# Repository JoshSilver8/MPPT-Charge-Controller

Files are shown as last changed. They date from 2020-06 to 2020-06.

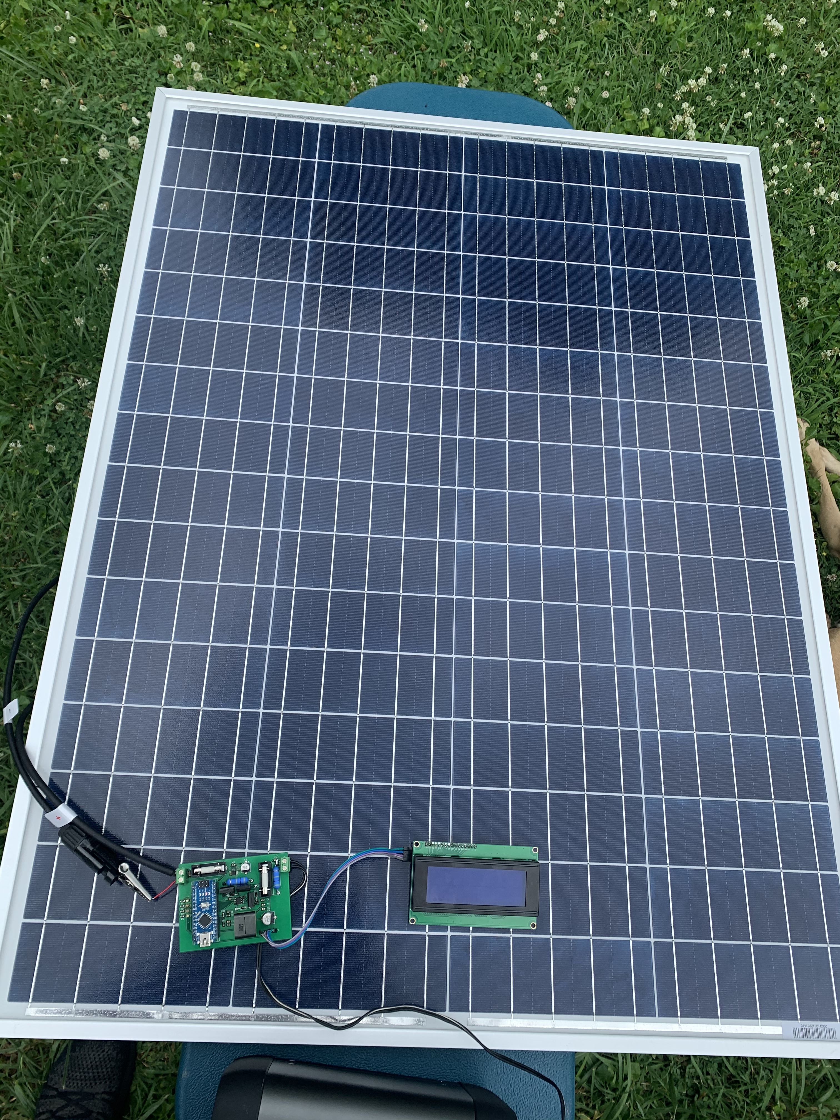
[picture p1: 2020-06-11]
Photos/Test 1.JPG

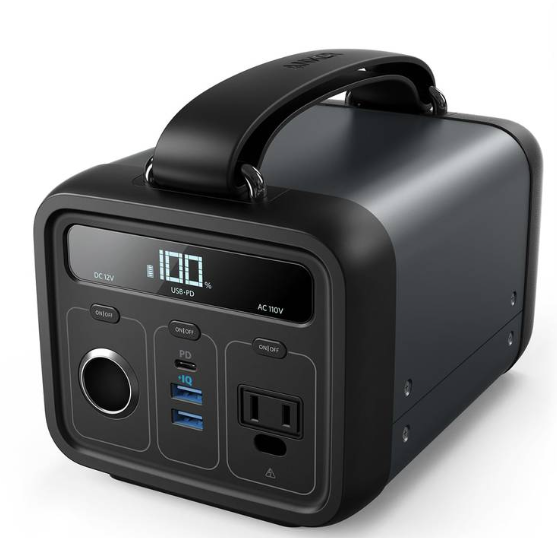
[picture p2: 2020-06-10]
Photos/Anker Powerhouse 200.png

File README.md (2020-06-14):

# MPPT-Charge-Controller

**Introduction** | This project was created in the scope of the the class ENGR 460 "Power Engineering" conducted through online learning at Walla Walla University. I was tasked with designing, building, and testing a *Solar Charge Controller*. For more information on the theory and circuit analysis of the design, please refer to the "Wiki" tab.

**Navigation** | This repository consists of several folders. In this "code" tab, you will find 2 main folders: Arduino & KiCAD. Within the Arduino file, you will find a folder containing the code that the charge controller runs on. The KiCAD folder contains the KiCAD project zip file which can be used to replicate the board used in this project

**Results** | The Charge Controller is in working order, there are some bugs with the Display output, and the board has to be slightly modified in this intial revision of the board. For more details visit the "Wiki" tab where the final indepth report is given.

**Status of Project** | Visit the "issues" tab to see errors and fixes for this project - which should provide a more in depth explanation for the quote "status" of the project. Can also visit the "Wiki" page or view the documentation files in the folders for a description of build and test process when troubleshooting issues.

**Credit** | This project was not without help, I would like to thank [Opengreenenergy](https://www.instructables.com/id/ARDUINO-SOLAR-CHARGE-CONTROLLER-Version-30/) for their charge controller design which helped me understand how to go about designing my controller. I referenced there block diagram and schematic. this was a great resource to start designing and understanding MPPT early in the project especially in the design of the Synchonous Buck Converter and upon looking at the two side my side after the fact they are more alike than I realized or wanted, this is likely due to choosing the same mosfets and mosfet driver which lookeed like a really good fit for my project, and after following the datasheets specification for those parts (whcih I can only assume that Opengreenenergy did the same) they looked similar when paired with the buck converter design used. however, it was too late in the project to make any radical design changes to revent the wheel. <br />
I'd also like to include [Tim Knowlan](https://github.com/Elexy/SerettaLabs/blob/master/mpptControler/ppt.pde) for allowing me to sample his code for this project. I needed to do some more editting to really squish out all the bugs I'm finding but I believe I was able to get the mosfets driving properly with this code indicated by the fact that I was getting 13.9V on testing which is within the maximum voltage out according the code. However, I have been unable to get the peripherals to function properly (LED's and I2C Display), this will hopefully be resolved in a future update (see Issues).

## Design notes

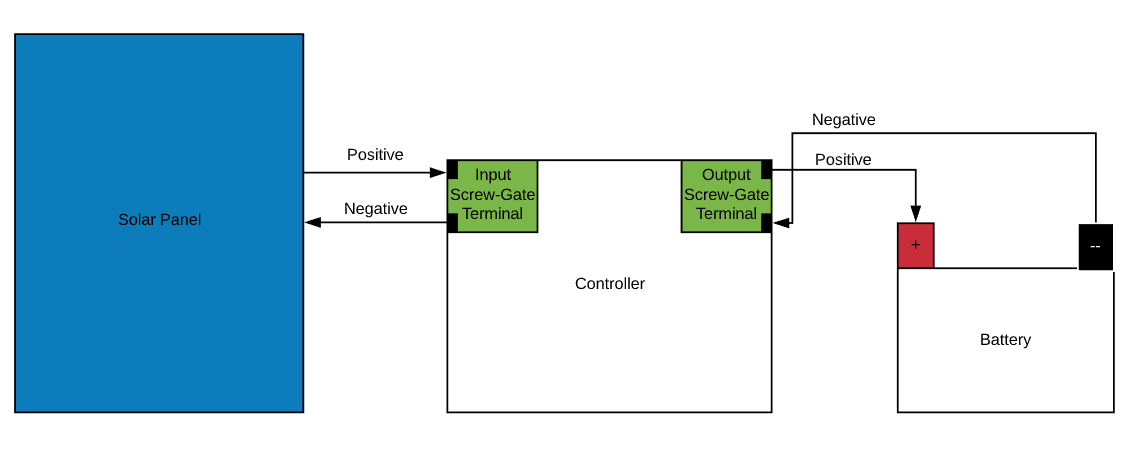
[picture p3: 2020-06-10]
Photos/Hookup.png

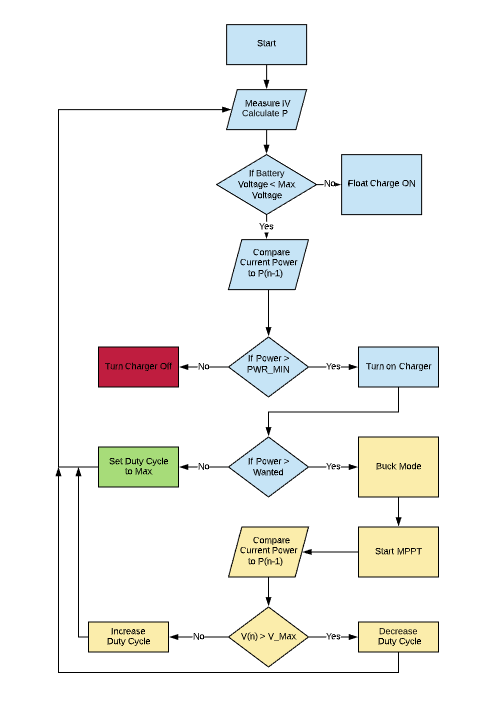
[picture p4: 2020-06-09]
Photos/MPPT Algorithm.png

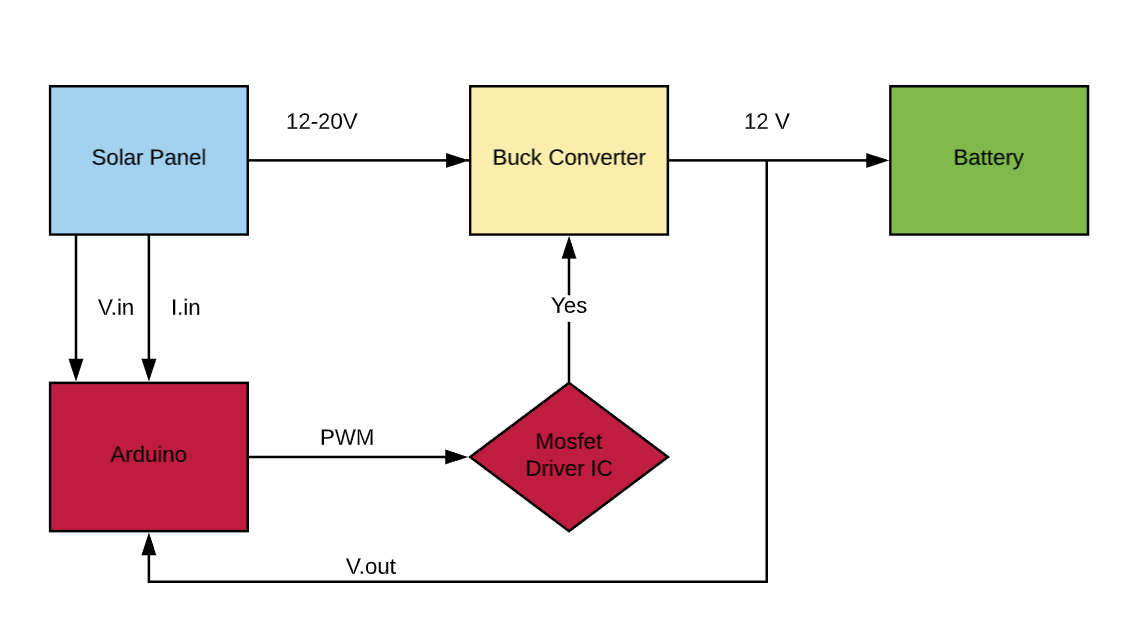
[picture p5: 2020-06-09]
Photos/MPPT Charge Controller Block Diagram.png

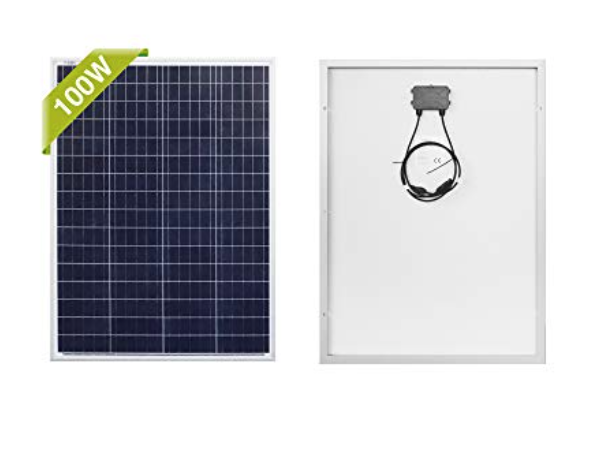
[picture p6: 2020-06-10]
Photos/PV Panel.png

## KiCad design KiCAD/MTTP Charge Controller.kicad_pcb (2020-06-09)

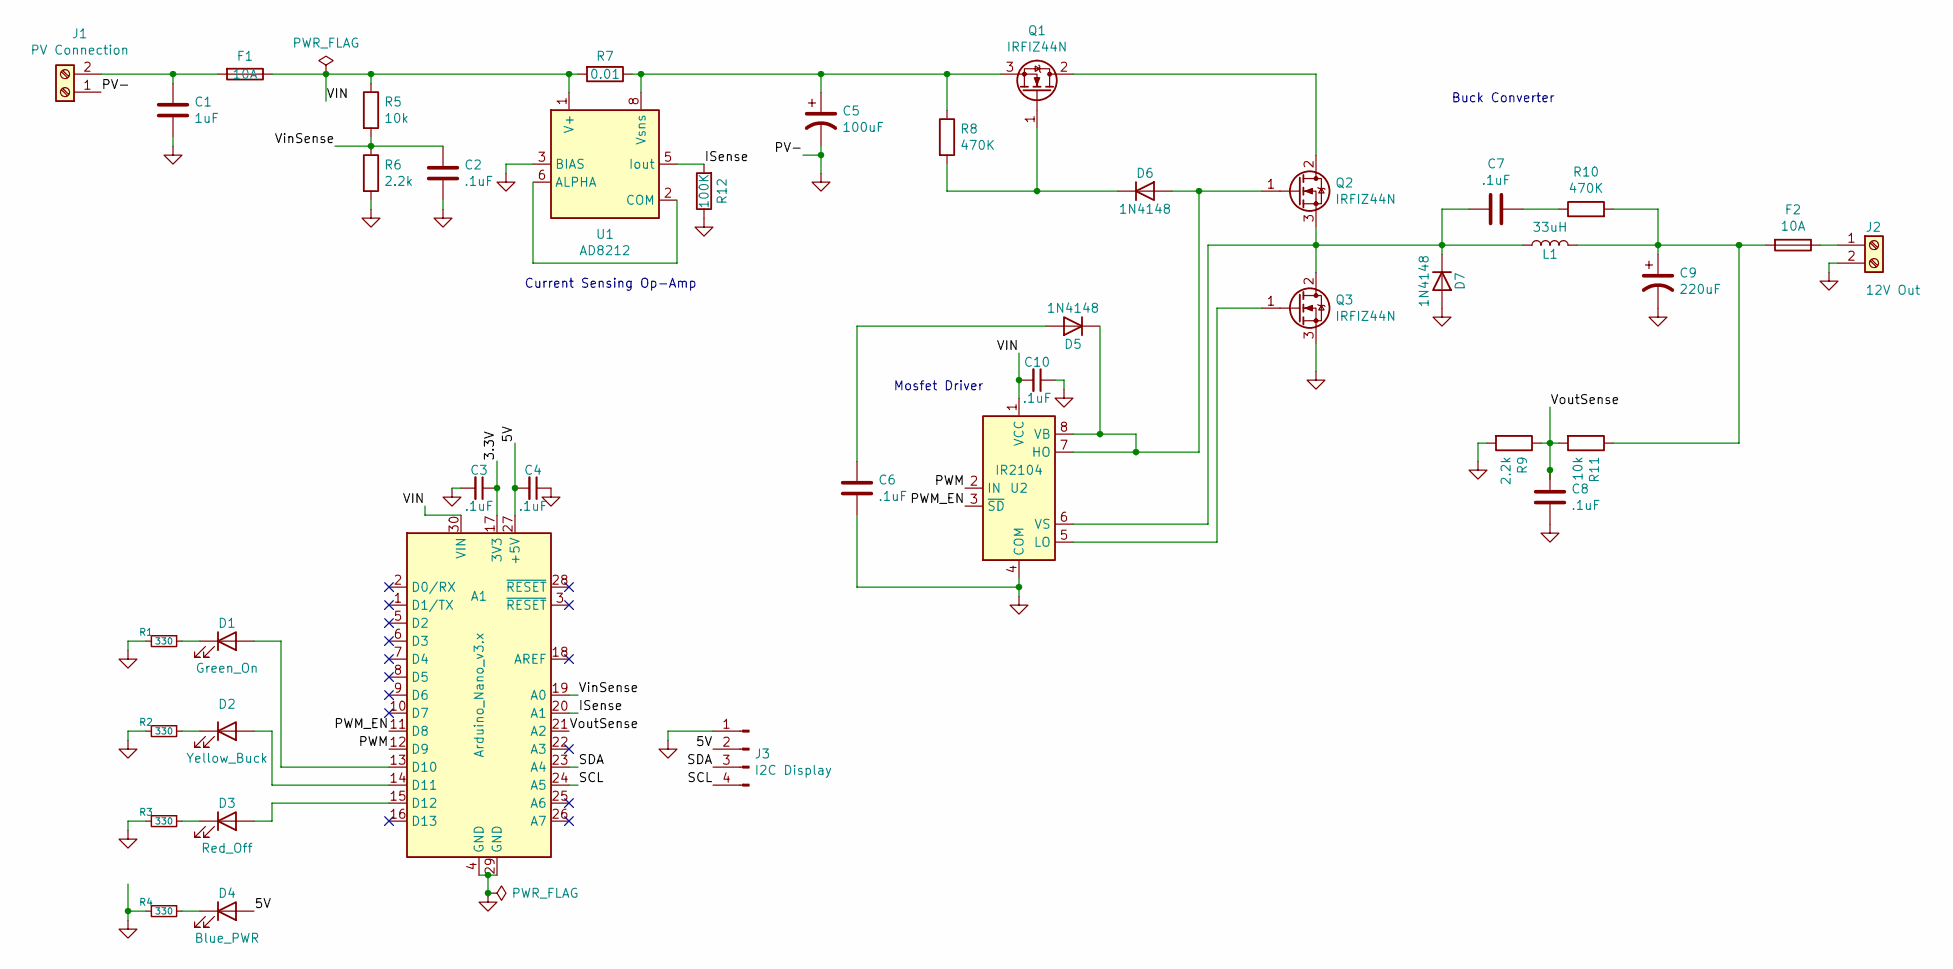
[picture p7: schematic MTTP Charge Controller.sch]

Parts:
A1: Arduino_Nano_v3.x; Arduino_Nano
C1: 1uF; C_1206_3216Metric
C2, C3, C4, C6, C7, C8, C10: .1uF; C_0805_2012Metric
C5: 100uF; CP_Elec_6.3x5.9
C9: 220uF; CP_Elec_8x6.9
D1: Green_On; LED_0805_2012Metric
D2: Yellow_Buck; LED_0805_2012Metric
D3: Red_Off; LED_0805_2012Metric
D4: Blue_PWR; LED_0805_2012Metric
D5, D6, D7: 1N4148; D_DO-35_SOD27_P10.16mm_Horizontal
F1, F2: 10A; Fuseholder_Cylinder-5x20mm_Stelvio-Kontek_PTF78_Horizontal_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
J1: PV Connection; SolderWirePad_1x02_P5.08mm_Drill1.5mm
J2: 12V Out; SolderWirePad_1x02_P5.08mm_Drill1.5mm
J3: I2C Display; PinHeader_1x04_P2.54mm_Vertical
L1: 33uH; DEP1519b_Inductor
Q1, Q2, Q3: IRFIZ44N; PinSocket_1x03_P2.54mm_Vertical
R1, R2, R3, R4: 330; R_0805_2012Metric
R5, R11: 10k; R_0805_2012Metric
R6, R9: 2.2k; R_0805_2012Metric
R7: 0.01; R_0805_2012Metric
R8, R10: 470K; R_Axial_DIN0411_L9.9mm_D3.6mm_P20.32mm_Horizontal
R12: 100K; R_0805_2012Metric
U1: AD8212; MSOP-8_3x3mm_P0.65mm
U2: IR2104; IR2104SPBF

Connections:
/3.3V: A1.17 (3V3), C3.1
/5V: A1.27 (+5V), C4.2, D4.2 (A), J3.2
/ISense: A1.20 (A1), R12.2, U1.5 (Iout)
/PWM: A1.12 (D9), U2.2 (IN)
/PWM_EN: A1.11 (D8), U2.3 (~SD)
/SCL: A1.24 (A5), J3.4
/SDA: A1.23 (A4), J3.3
/VIN: A1.30 (VIN), C10.2, F1.1, R5.1, R7.2, U1.1 (V+), U2.1 (VCC)
/VinSense: A1.19 (A0), C2.2, R5.2, R6.1
/VoutSense: A1.21 (A2), C8.1, R9.1, R11.2
GND: A1.4 (GND), A1.29 (GND), C1.1, C2.1, C3.2, C4.1, C5.2, C6.1, C8.2, C9.2, C10.1, D7.2 (A), J1.1, J2.2, J3.1, Q3.3 (S), R1.2, R2.2, R3.2, R4.2, R6.2, R9.2, R12.1, U1.3 (BIAS), U2.4 (COM)
unnamed: A1.13 (D10), D1.2 (A)
unnamed: A1.14 (D11), D2.2 (A)
unnamed: A1.15 (D12), D3.2 (A)
unnamed: C1.2, F1.2, J1.2
unnamed: C5.1, Q1.3 (S), R7.1, R8.1, U1.8 (Vsns)
unnamed: C6.2, D5.2 (A)
unnamed: C7.1, D7.1 (K), L1.1, Q2.3 (S), Q3.2 (D), U2.6 (VS)
unnamed: C7.2, R10.1
unnamed: C9.1, F2.2, L1.2, R10.2, R11.1
unnamed: D1.1 (K), R1.1
unnamed: D2.1 (K), R2.1
unnamed: D3.1 (K), R3.1
unnamed: D4.1 (K), R4.1
unnamed: D5.1 (K), D6.2 (A), Q2.1 (G), U2.7 (HO), U2.8 (VB)
unnamed: D6.1 (K), Q1.1 (G), R8.2
unnamed: F2.1, J2.1
unnamed: Q1.2 (D), Q2.2 (D)
unnamed: Q3.1 (G), U2.5 (LO)
unnamed: U1.2 (COM), U1.6 (ALPHA)

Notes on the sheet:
Buck Converter
Mosfet Driver
Current Sensing Op-Amp

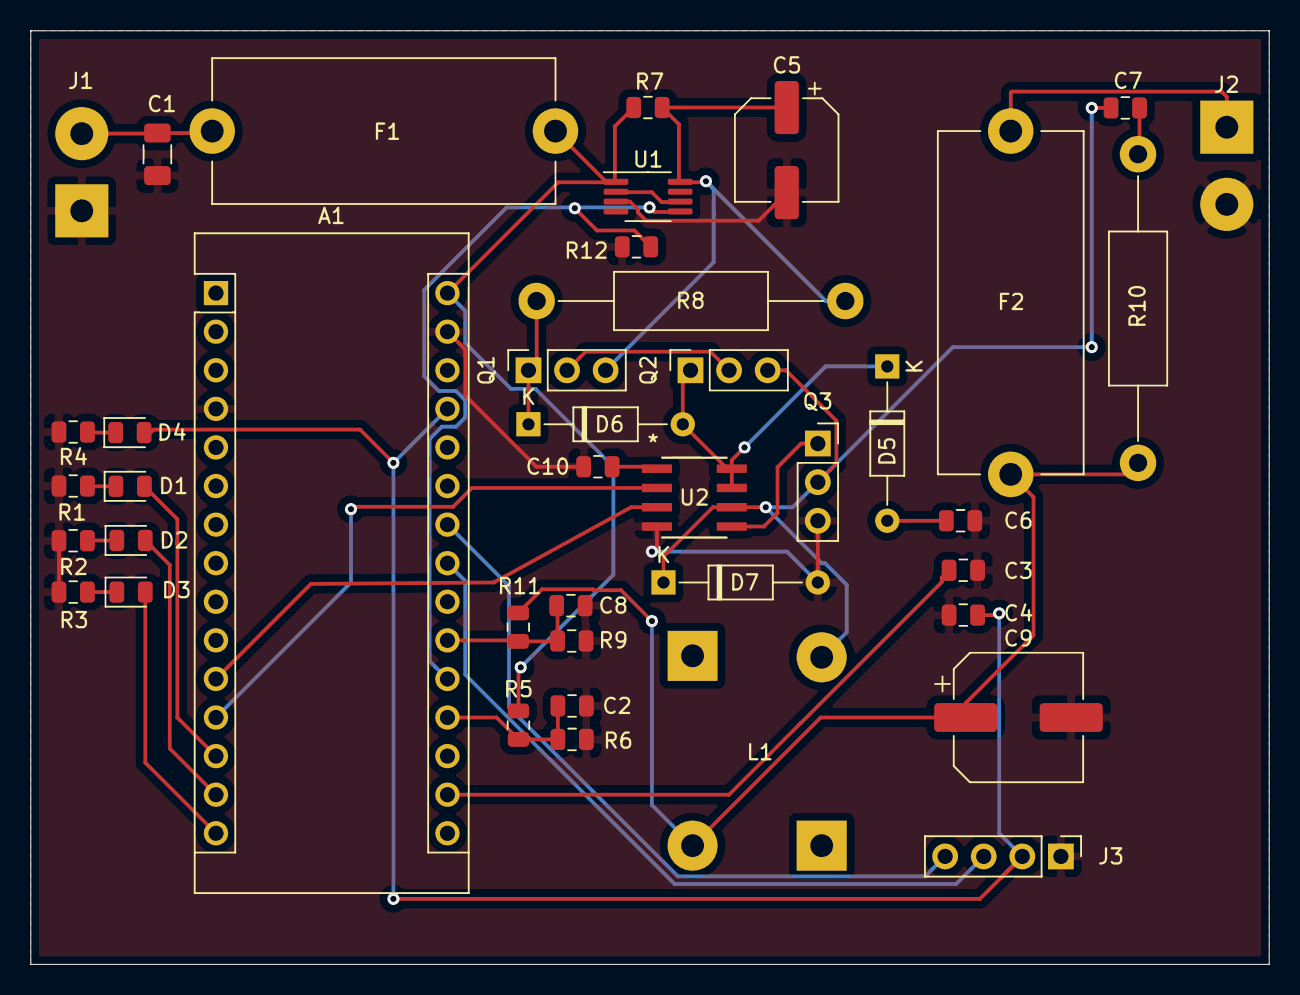
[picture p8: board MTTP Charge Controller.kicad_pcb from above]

Board: 2 copper layers, 81.5 x 61.5 mm, 41 parts (0 on the bottom side), 30 nets.

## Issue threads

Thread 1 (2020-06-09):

MOSFETS footprint incorrect

JoshSilver8, 2020-06-09:
I was getting an output voltage of around .5V which was obviously a far cry away from the expected voltage of around 12-14V when the input voltage was around 18V.

In troubleshooting, I discovered that Pins 1 and 2 need to be switched in order for the MOSFETs to function properly.

On a Rev 1 Board, this can be resolved by removing all three MOSFETS  using a male to female jumper cable to manually reverse the pins and this issue can be resolved.

Closed 2020-06-09.

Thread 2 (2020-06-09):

Missing Traces

JoshSilver8, 2020-06-09:
There is a missing trace between pin 1 on R10 and Pin 2 on R7 these components are very close together so the easiest way to fix this is to apply a liberal amount of solder to bridge the two parts, just ensure that you do not put so much that you bring with Pin 1 on C7 as well.

JoshSilver8, 2020-06-09:
The wiring is quite messed on all four of the LEDs the following fixes are needed for the LEDs to function as intended. this fix is not necessary as the 20x4 character screen will tell you the charge state the device is in.

D1 (Green)  - Add a jumper wire from Right pad on D1 to Right pad on R1
D2 (Yellow) -  Add a jumper wire from Left pad on D2 to Left pad on R2
D3 (Red)     -  Add a jumper wire from Right pad on D3 to Right pad on R3
D4 (Blue)    - Bridge left pad D4 with Right Pad of R4

I honestly don't know how I messed this one up so bad, all I can say is **never** order boards at 2am,
review your board in the morning then send it out.

Closed 2020-06-09.

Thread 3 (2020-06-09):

Display Not Reporting Info

JoshSilver8, 2020-06-09:
The 20x4 character display is not outputting information, more research has to be done to determine the cause of this, however, the output of the charge controller is at the expected 14.1V which shows that the Buck converter is operating as expected. This issue will be updated when the code is fixed.

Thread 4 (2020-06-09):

Missing Resistor

JoshSilver8, 2020-06-09:
R12 is added into Rev 2 to properly run the AD8212 Current Senor, this is a 100k resistor that controls the gain as described in the "theory of operation" in the datasheet. To correct add a THT 100k resistor from Pin 5 to GND, without this, the current will not be properly sensed and therefore the algorithm will not work.

Closed 2020-06-09.

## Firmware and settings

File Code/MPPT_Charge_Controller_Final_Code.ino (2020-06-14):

#include <LiquidCrystal.h>
#include <Wire.h>

//------------------------------------------------------------------------------------------------------
// Joshua Silver
// MPPT Solar Battery Charger Controller
// Power Electronics ENGR 460
// Rob Frohne
//------------------------------------------------------------------------------------------------------
// Intially Wrote by Tim Nolan
// Modified by Joshua Silver
//------------------------------------------------------------------------------------------------------

#include "TimerOne.h"          // using Timer1 library from http://www.arduino.cc/playground/Code/Timer1
#include <wire.h>


//------------------------------------------------------------------------------------------------------
// definitions

#define SOL_AMPS_CHAN 1               // Defining the adc channel to read solar amps
#define SOL_VOLTS_CHAN 0              //                                 -solar volts
#define BAT_VOLTS_CHAN 2              //                                 -battery volts

#define AVG_NUM 8                     // number of iterations of the adc routine to average the adc readings
#define SOL_AMPS_SCALE 7              // the scaling value for raw adc reading to get solar amps scaled by 100
#define SOL_VOLTS_SCALE 27            //                                             -solar volts scaled by 100
#define BAT_VOLTS_SCALE 27            //                                             -battery volts scaled by 100

#define PWM_PIN 9                     // the output pin for the pwm (only pin 9 avaliable for timer 1 at 50kHz)
#define PWM_ENABLE_PIN 8              // pin used to control shutoff function of the IR2104 MOSFET driver (hight the mosfet driver is on)
#define PWM_FULL 1023                 // the actual value used by the Timer1 routines for 100% pwm duty cycle
#define PWM_MAX 100                   
#define PWM_MIN 60                    // the value for pwm duty cyle below this value the current running in the system is = 0)
#define PWM_START 90                 
#define PWM_INC 1                     //the pwm increment

#define TRUE 1
#define FALSE 0
#define ON TRUE
#define OFF FALSE

#define TURN_ON_MOSFETS digitalWrite(PWM_ENABLE_PIN, HIGH)      // enable MOSFET driver
#define TURN_OFF_MOSFETS digitalWrite(PWM_ENABLE_PIN, LOW)      // disable MOSFET driver

#define ONE_SECOND 50000             //count for number of interrupt in 1 second on interrupt period of 20us

#define LOW_SOL_WATTS 500            //values here are scaled by 100 i.e 500 = 5.00 watts
#define MIN_SOL_WATTS 100            
#define MIN_BAT_VOLTS 800                   
#define MAX_BAT_VOLTS 1410           
#define HIGH_BAT_VOLTS 1300          
#define OFF_NUM 9                  // number of iterations of off charger state
  
//------------------------------------------------------------------------------------------------------
//Defining led pins for indication
#define LED_RED_OFF 12 //Off
#define LED_GREEN 10   //On
#define LED_YELLOW 11  //Buck

  
//------------------------------------------------------------------------------------------------------
// global variables

int ledPin = 13;                      
int ledPin_jc2 = 5;                  
int ledPin_jc3 = 6;                   


int count = 0;
int pwm = 0;                          //pwm duty cycle 0-100%
int sol_amps;                         // solar amps scaled by 100
int sol_volts;                        // solar volts scaled by 100
int bat_volts;                        // battery volts scaled by 100
int sol_watts;                        // solar watts scaled by 100
int old_sol_watts = 0;                // solar watts from previous time through ppt routine scaled by 100
unsigned int seconds = 0;             // seconds from timer routine
unsigned int prev_seconds = 0;        // seconds value from previous pass
unsigned int interrupt_counter = 0;   // counter for 20us interrrupt
boolean led_on = TRUE;
int led_counter = 0;
int delta = PWM_INC;                  // variable used to modify pwm duty cycle for the ppt algorithm
                                      // enumerated variable that holds state for charger state machine
enum charger_mode {off, on, buck, bat_float} charger_state;    
//------------------------------------------------------------------------------------------------------
// This routine is automatically called at powerup/reset
//------------------------------------------------------------------------------------------------------
void setup()                            // run once, when the sketch starts
{
  pinMode(LED_RED_OFF, OUTPUT);
  pinMode(LED_GREEN, OUTPUT);
  pinMode(LED_YELLOW, OUTPUT);
  
  pinMode(ledPin, OUTPUT);             // sets the digital pin as output
  pinMode(ledPin_jc2, OUTPUT);         // sets the digital pin as output
  pinMode(PWM_ENABLE_PIN, OUTPUT);     // sets the digital pin as output
  Timer1.initialize(20);               // initialize timer1, and set a 20uS period
  Timer1.pwm(PWM_PIN, 0);              // setup pwm on pin 9, 0% duty cycle
  TURN_ON_MOSFETS;                     //turn on MOSFET driver chip
  Timer1.attachInterrupt(callback);    // attaches callback() as a timer overflow interrupt
  Serial.begin(9600);                  // open the serial port at 38400 bps:
  pwm = PWM_START;                     //starting value for pwm  
  charger_state = on;                  // start with charger state as on
}
//------------------------------------------------------------------------------------------------------
// This is interrupt service routine for Timer1 that occurs every 20uS.
//
//------------------------------------------------------------------------------------------------------
void callback()
{
  if (interrupt_counter++ > ONE_SECOND) {        //increment interrupt_counter until one second has passed
    interrupt_counter = 0;  
    seconds++;                                   //then increment seconds counter
  }
}
//------------------------------------------------------------------------------------------------------
// This routine reads and averages the analog inputs for this system, solar volts, solar amps and 
// battery volts. 
//------------------------------------------------------------------------------------------------------
int read_adc(int channel){
  
  int sum = 0;
  int temp;
  int i;
  
  for (i=0; i<AVG_NUM; i++) {            // loop through reading raw adc values AVG_NUM number of times  
    temp = analogRead(channel);          
    sum += temp;                        
    delayMicroseconds(50);                
  }
  return(sum / AVG_NUM);                // divide sum by AVG_NUM to get average and return it
}
//-----------------------------------------------------------------------------------
// This function prints int that was scaled by 100 with 2 decimal places
//-----------------------------------------------------------------------------------
void print_int100_dec2(int temp) {

  Serial.print(temp/100,DEC);         // divide by 100 and print interger value
  Serial.print(".");
  if ((temp%100) < 10) {              // if fractional value has only one digit
    Serial.print("0");                
    Serial.print(temp%100,DEC);       // get remainder and print fraction
  }else
    Serial.print(temp%100,DEC);       // get remainder and print fraction
  
}
//------------------------------------------------------------------------------------------------------
// This routine uses the Timer1.pwm function to set the pwm duty cycle.
//------------------------------------------------------------------------------------------------------
void set_pwm_duty(void) {

  if (pwm > PWM_MAX) 			  
    pwm = PWM_MAX;		
  else if (pwm < PWM_MIN)		
    pwm = PWM_MIN;
 
  if (pwm < PWM_MAX) 
    Timer1.pwm(PWM_PIN,(PWM_FULL * (long)pwm / 100), 20); // use Timer1 routine to set pwm duty cycle at 20uS period
  else if (pwm == PWM_MAX) 			                     // if pwm set to 100% it will be on full but we have 
    Timer1.pwm(PWM_PIN,(PWM_FULL - 1), 1000);          // keep switching so set duty cycle at 99.9% and slow down to 1000uS period            
  												
}													
//------------------------------------------------------------------------------------------------------
// This routine prints all the data out to the serial port.
//------------------------------------------------------------------------------------------------------
void print_data(void) {
  
  Serial.print(seconds,DEC);
  Serial.print("  ");

  Serial.print("Charging State - ");
  if (charger_state == on) Serial.print("on   ");
  else if (charger_state == off) Serial.print("off  ");
  else if (charger_state == buck) Serial.print("buck ");
  else if (charger_state == bat_float) Serial.print("float");
  Serial.print("  ");
  lcd.setCursor(0, 0); // Set the cursor on the first column and first row.
  lcd.print("Hello World!"); // Print the string "Hello World!"
  Serial.print("PWM = ");
  Serial.print(pwm,DEC);
  Serial.print("  ");

  Serial.print("Current (panel) = ");
  print_int100_dec2(sol_amps);
  Serial.print("  ");

  Serial.print("Voltage (panel) = ");
  //Serial.print(sol_volts,DEC);
  print_int100_dec2(sol_volts);
  Serial.print("  ");

  Serial.print("Power (panel) = ");
  //Serial.print(sol_volts,DEC);
  print_int100_dec2(sol_watts);
  Serial.print("  ");

  Serial.print("Battery Voltage = ");
  //Serial.print(bat_volts,DEC);
  print_int100_dec2(bat_volts);
  Serial.print("  ");

  Serial.print("\n\r");
}
//------------------------------------------------------------------------------------------------------
// This routine reads all the analog input values for the system. Then it multiplies them by the scale
// factor to get actual value in volts or amps. 
//------------------------------------------------------------------------------------------------------
void read_data(void) {
  
  sol_amps  =  ((read_adc(SOL_AMPS_CHAN)  * SOL_AMPS_SCALE) + 5) / 10;    
  sol_volts = ((read_adc(SOL_VOLTS_CHAN) * SOL_VOLTS_SCALE) + 5) / 10;   
  bat_volts = ((read_adc(BAT_VOLTS_CHAN) * BAT_VOLTS_SCALE) + 5) / 10;    
  sol_watts = (int)((((long)sol_amps * (long)sol_volts) + 50) / 100);                     
}

//------------------------------------------------------------------------------------------------------
// This routine is the charger state machine. It has four states on, off, buck and float.
// It's called once each time through the main loop to see what state the charger should be in.
// The battery charger can be in one of the following four states:
// 
//  On State - this is charger state for MIN_SOL_WATTS < solar watts < LOW_SOL_WATTS. In this state the solar 
//      watts input is too low for the buck charging state but not low enough to go into the off state. 
//      In this state we just set the pwm = 99.9% to get the most of low amount of power available.

//  buck State - this is charger state for solar watts > MIN_SOL_WATTS. This is where we do the buck of the battery
//      charging and where we run the Peak Power Tracking alogorithm. In this state we try and run the maximum amount
//      of current that the solar panels are generating into the battery.

//  Float State - As the battery charges it's voltage rises. When it gets to the MAX_BAT_VOLTS we are done with the 
//      buck battery charging and enter the battery float state. In this state we try and keep the battery voltage
//      at MAX_BAT_VOLTS by adjusting the pwm value. If we get to pwm = 100% it means we can't keep the battery 
//      voltage at MAX_BAT_VOLTS which probably means the battery is being drawn down by some load so we need to back
//      into the buck charging mode.

//  Off State - This is state that the charger enters when solar watts < MIN_SOL_WATTS. The charger goes into this
//      state when there is no more power being generated by the solar panels. The MOSFETs are turned
//      off in this state so that power from the battery doesn't leak back into the solar panel. 
//------------------------------------------------------------------------------------------------------
void run_charger(void) {
  
  static int off_count = OFF_NUM;

  switch (charger_state) {
    case on:                                        
      if (sol_watts < MIN_SOL_WATTS) {                  //if watts input from the solar panel is less than
        charger_state = off;                            //the minimum solar watts then 
        off_count = OFF_NUM;                            //go to the charger off state
        TURN_OFF_MOSFETS; 
      }
      else if (bat_volts > MAX_BAT_VOLTS)                 //else if the battery voltage has gotten above the float
        charger_state = bat_float;                         //battery float voltage go to the charger battery float state
      else if (sol_watts < LOW_SOL_WATTS) {               //else if the solar input watts is less than low solar watts
        pwm = PWM_MAX;                                    //it means there is not much power being generated by the solar panel
        set_pwm_duty();			                               //so we just set the pwm = 100% so we can get as much of this power as possible
      }                                                    //and stay in the charger on state
      else {                                          
        pwm = ((bat_volts * 10) / (sol_volts / 10)) + 5;   //else if we are making more power than low solar watts figure out what the pwm
        charger_state = buck;                              //value should be and change the charger to buck state 
      }
      break;
    case buck:
      if (sol_watts < MIN_SOL_WATTS) {               //if watts input from the solar panel is less than
        charger_state = off;                        //the minimum solar watts then it is getting dark so
        off_count = OFF_NUM;                        //go to the charger off state
        TURN_OFF_MOSFETS; 
      }
      else if (bat_volts > MAX_BAT_VOLTS)         //else if the battery voltage has gotten above the float
        charger_state = bat_float;                //battery float voltage go to the charger battery float state
      else if (sol_watts < LOW_SOL_WATTS) {      //else if the solar input watts is less than low solar watts
        charger_state = on;                      //it means there is not much power being generated by the solar panel
        TURN_ON_MOSFETS;                         //so go to charger on state
      }
      else {                                     // this is where we do the Peak Power Tracking using Maximum Power Point algorithm
        if (old_sol_watts >= sol_watts) {        //  if previous watts are greater change the value of
          delta = -delta;			                    // delta to make pwm increase or decrease to maximize watts
        }
        pwm += delta;                           // add delta to change PWM duty cycle for PPT algorythm (compound addition)
        old_sol_watts = sol_watts;              // load old_watts with current watts value for next time
        set_pwm_duty();			                  	// set pwm duty cycle to pwm value
      }
      break;
    case bat_float:
      if (sol_watts < MIN_SOL_WATTS) {          //if watts input from the solar panel is less than
        charger_state = off;                    //the minimum solar watts then it is getting dark so
        off_count = OFF_NUM;                    //go to the charger off state
        set_pwm_duty();					
        TURN_OFF_MOSFETS; 
      }
      else if (bat_volts > MAX_BAT_VOLTS) {    //since we're in the battery float state if the battery voltage
        pwm -= 1;                               //is above the float voltage back off the pwm to lower it   
        set_pwm_duty();					
      }
      else if (bat_volts < MAX_BAT_VOLTS) {    //else if the battery voltage is less than the float voltage
        pwm += 1;                              //increment the pwm to get it back up to the float voltage
        set_pwm_duty();					
        if (pwm >= 100)                        //if pwm gets up to 100 it means we can't keep the battery at
          charger_state = buck;                //float voltage so jump to charger buck state to charge the battery
        
      }
      break;
    case off:                                  //when we jump into the charger off state, off_count is set with OFF_NUM
      if (off_count > 0)                       //this means that we run through the off state OFF_NUM of times with out doing
        off_count--;                           //anything, this is to allow the battery voltage to settle down to see if the  
                                               //battery has been disconnected
      else if ((bat_volts > HIGH_BAT_VOLTS) && (bat_volts < MAX_BAT_VOLTS) && (sol_volts > bat_volts)) {
        charger_state = bat_float;             //if battery voltage is still high and solar volts are high
        set_pwm_duty();		                     //change charger state to battery float			
        TURN_ON_MOSFETS; 
      }    
      else if ((bat_volts > MIN_BAT_VOLTS) && (bat_volts < MAX_BAT_VOLTS) && (sol_volts > bat_volts)) {
        pwm = PWM_START;                        //if battery volts aren't quite so high but we have solar volts
        set_pwm_duty();		                    	//greater than battery volts showing it is day light then	
        charger_state = on;                     //change charger state to on so we start charging
        TURN_ON_MOSFETS; 
      }                                         
      break;
    default:
      TURN_OFF_MOSFETS;                         //else stay in the off state
      break;
  }
}

//------------------------------------------------------------------------------------------------------
//This function displays the currnet state with the help ot the 3 LEDs
//------------------------------------------------------------------------------------------------------
void led_output(void)
{
  if(charger_state == on){
      leds_off_all();
      digitalWrite(LED_GREEN, HIGH);
  } else if(charger_state == off){
      leds_off_all();
      digitalWrite(LED_RED_OFF, HIGH);  
  } else if(charger_state == buck){
      leds_off_all;
      digitalWrite(LED_YELLOW, HIGH);
  } else if(charger_state == bat_float){
      leds_off_all();
      digitalWrite(LED_GREEN, HIGH);
      digitalWrite(LED_RED_OFF, HIGH);
      digitalWrite(LED_YELLOW, HIGH);
  }
}

//------------------------------------------------------------------------------------------------------
// This function is used to turn all the leds off
//------------------------------------------------------------------------------------------------------
void leds_off_all(void)
{
  digitalWrite(LED_GREEN, LOW);
  digitalWrite(LED_RED_OFF, LOW);
  digitalWrite(LED_YELLOW, LOW);
}

//------------------------------------------------------------------------------------------------------
// Main loop.
//------------------------------------------------------------------------------------------------------
void loop()                         
{
  read_data();                  
  run_charger();                      
  print_data();                       
  led_output();
  
}

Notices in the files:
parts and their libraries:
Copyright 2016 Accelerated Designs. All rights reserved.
